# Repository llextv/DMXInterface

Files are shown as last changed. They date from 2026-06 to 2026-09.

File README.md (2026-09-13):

# DMX Interface — ArtNet to DMX Converter

A DIY Ethernet-to-DMX interface designed to convert **Art-Net DMX data into physical DMX512 outputs**.

The goal of this project is to create an affordable alternative to commercial Art-Net to DMX interfaces while keeping the hardware simple, easy to assemble and fully customizable.

---

# Overview

## What does this project do?

This interface acts as a bridge between an Ethernet network and DMX lighting equipment.

Instead of connecting a lighting controller directly to a DMX cable, the controller sends DMX data over an Ethernet network using the **Art-Net protocol**.

This makes the interface particularly useful for **DMX lighting, stage lighting, DJ setups, architectural lighting and other Art-Net compatible applications**.

---

# Hardware

The complete Bill of Materials is available in:

[BOM.csv](BOM.csv)

The detailed BOM is also available at the end of this document.

---

# Mechanical Design

The enclosure was designed to be **fully 3D printable**.

The objective was to avoid requiring specialized machining or industrial manufacturing equipment.

The enclosure can therefore be reproduced using a standard FDM 3D printer.

## Case

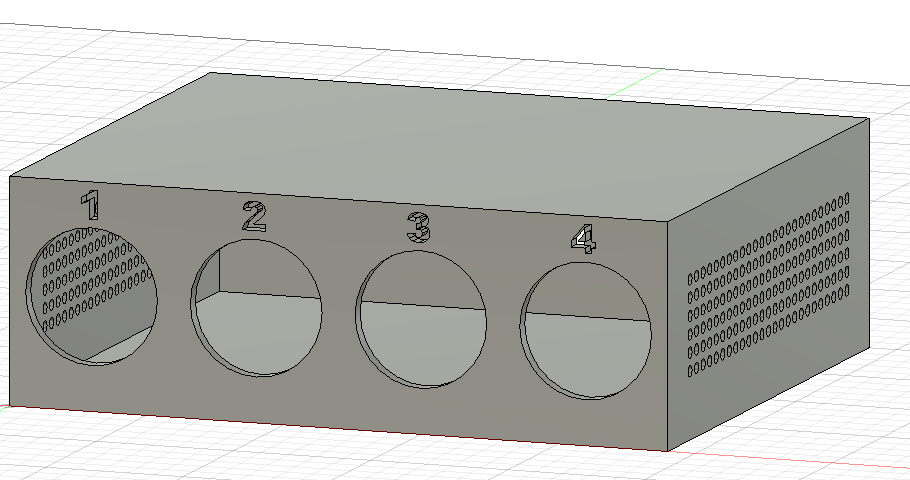
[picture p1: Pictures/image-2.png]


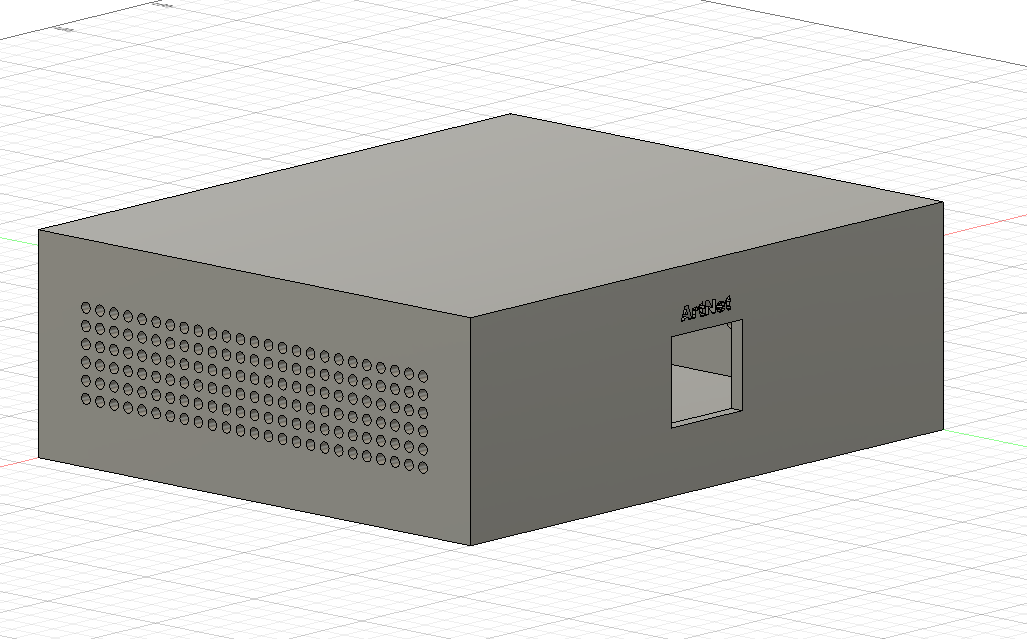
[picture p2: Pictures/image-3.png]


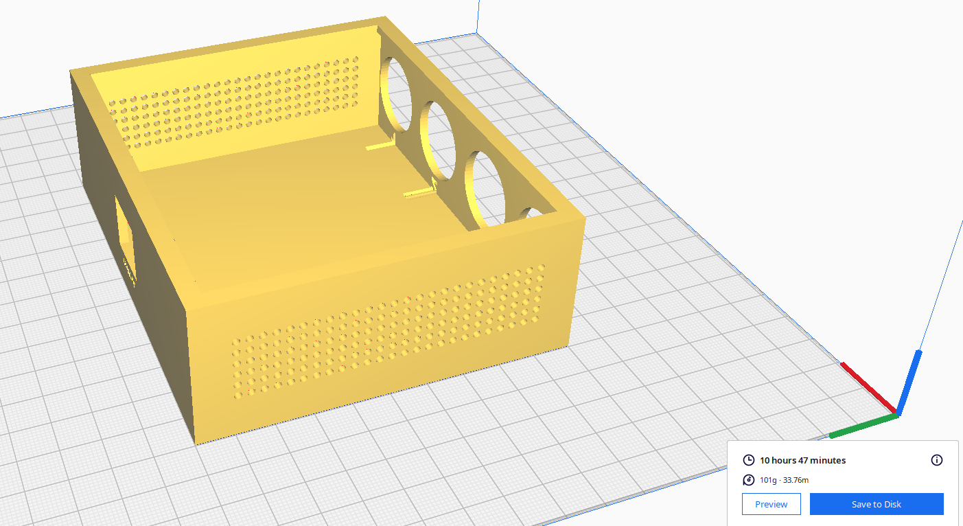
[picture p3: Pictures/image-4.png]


---

# CAD Files

The CAD files are provided in STEP format so that the enclosure can be modified using most modern CAD software.

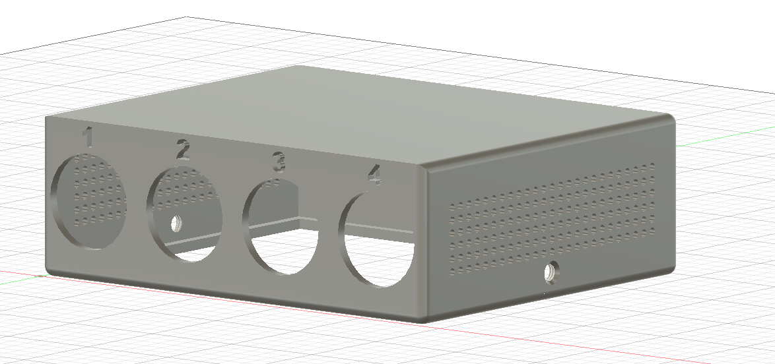
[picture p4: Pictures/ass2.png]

* [Bottom DMX Interface](cad/BottomDMXInterface.step)
* [DMX Interface Enclosure](cad/DMXInterface.step)
* [Assembly](cad\AssemblageDMXInterfaceF.step)

---

# Electronic Design

## Schematic

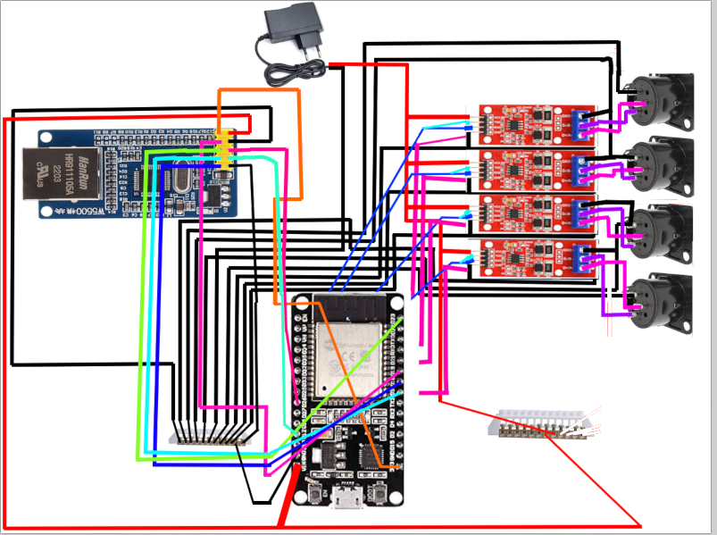
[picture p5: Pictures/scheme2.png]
DMX Interface schematic


The electronics are divided into three main sections:

---

# Firmware

The firmware is responsible for converting Art-Net packets into DMX data.

The current implementation uses an ESP32 together with the following libraries:

* `Ethernet_Generic`
* `ArtnetWifi`
* `ESP32DMX`

---

# Firmware Configuration

The firmware currently uses a static IP address:

```cpp
IPAddress ip(192, 168, 1, 50);
```

This can be changed to match the network used for the lighting setup.

The W5500 chip select pin is configured as:

```cpp
#define W5500_CS 10
```

The four DMX transmit pins are:

```cpp
#define DMX1_TX 4
#define DMX2_TX 5
#define DMX3_TX 6
#define DMX4_TX 7
```

These values must match the actual wiring of the ESP32.

---

# Main Firmware

```c
#include <SPI.h>
#include <Ethernet_Generic.h>
#include <ArtnetWifi.h>
#include <ESP32DMX.h>

#define W5500_CS 10

byte mac[] = {
  0xDE, 0xAD, 0xBE, 0xEF, 0xFE, 0x01
};

IPAddress ip(192, 168, 1, 50);

#define DMX1_TX 4
#define DMX2_TX 5
#define DMX3_TX 6
#define DMX4_TX 7

ESP32DMX dmx1;
ESP32DMX dmx2;
ESP32DMX dmx3;
ESP32DMX dmx4;

uint8_t universe0[512];
uint8_t universe1[512];
uint8_t universe2[512];
uint8_t universe3[512];

ArtnetWifi artnet;

void onDmxFrame(
  uint16_t universe,
  uint16_t length,
  uint8_t sequence,
  uint8_t* data
) {
  switch (universe) {
    case 0:
      memcpy(universe0, data, length);

      for (int i = 0; i < length; i++)
        dmx1.write(i + 1, data[i]);

      break;

    case 1:
      memcpy(universe1, data, length);

      for (int i = 0; i < length; i++)
        dmx2.write(i + 1, data[i]);

      break;

    case 2:
      memcpy(universe2, data, length);

      for (int i = 0; i < length; i++)
        dmx3.write(i + 1, data[i]);

      break;

    case 3:
      memcpy(universe3, data, length);

      for (int i = 0; i < length; i++)
        dmx4.write(i + 1, data[i]);

      break;
  }
}

void setup()
{
  Serial.begin(115200);

  Serial.println("DMX Interface Starting");

  Ethernet.init(W5500_CS);
  Ethernet.begin(mac, ip);

  Serial.print("IP: ");
  Serial.println(Ethernet.localIP());

  dmx1.init(DMX1_TX);
  dmx2.init(DMX2_TX);
  dmx3.init(DMX3_TX);
  dmx4.init(DMX4_TX);

  artnet.begin();
  artnet.setArtDmxCallback(onDmxFrame);

  Serial.println("ArtNet Ready");
}

void loop()
{
  artnet.read();
}
```

---

# BOM

| Category | Item | Quantity | Unit Price (€) | Total (€) | Notes |
| --- | --- | ---: | ---: | ---: | --- |
| Communication | W5500 | 1 | 3.89 | 3.89 | Ethernet controller |
| Communication | MAX3485 Module RS-485 | 4 | 1.40 | 5.60 | One per DMX output |
| Controls | ESP-WROOM-32 | 1 | 5.89 | 5.89 | Main controller |
| Connectique | XLR 3Pin Panel Mount Connectors Female | 4 | 1.05 | 4.19 | Lot of 4 connectors |
| Power | 5V 2A Power Supply | 1 | 2.99 | 2.99 | Main power supply |
| Prototype | 12 Holes Bridge | 2 | 2.37 | 4.74 | Electrical connections |
| **TOTAL** | | | | **27.30 €** | |

---

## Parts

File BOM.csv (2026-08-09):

Categorie | Article | Quantite | Prix_Unitaire_EUR | Prix_Total_EUR | Notes | URL
Communication | W5500 | 1 | 3.89 | 3.89 |  | https://fr.aliexpress.com/item/1005009353017777.html
Communication | MAX3485 Module RS-485 | 4 | 1.40 | 5.6 |  | https://fr.aliexpress.com/item/1005006007545162.html
Controls | ESP-WROOM-32 | 1 | 5.89 | 5.89 |  | https://fr.aliexpress.com/item/1005012697513614.html
Connectique | XLR 3Pin Panel Mount Connectors Female | 4 | 1.05 | 4.19 | Lot de 4 connecteurs | https://fr.aliexpress.com/item/1005008919369057.html
Power | Alimentation 5V 2A | 1 | 2.99 | 2.99 |  | https://fr.aliexpress.com/item/1005005539475429.html
Prototype | 12 Holes Bridge | 2 | 2.37 | 4.74 |  | https://fr.aliexpress.com/item/1005001742109041.html
TOTAL |  |  | 27,3

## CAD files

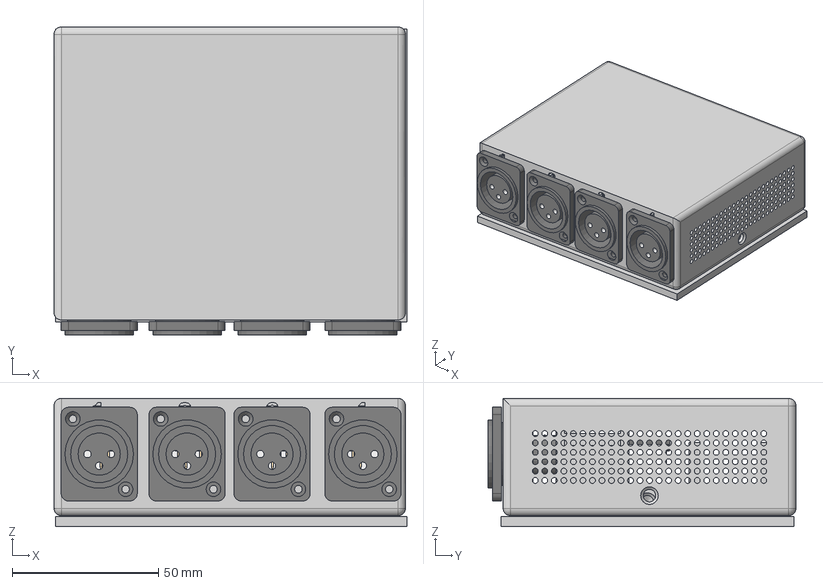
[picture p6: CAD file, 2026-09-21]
cad/AssemblageDMXInterfaceF.step
120.5 x 105.2 x 43.7 mm
plug_rj45
ESPBlock
BottomDMXInterface
DMXInterface
2 PIN - DG306-5 - PITCH 5 mm v1 x 4
Black Pin H 2.5mm-6mm-3mm x4 v1 x 8
MAX485CUA v1 x 4
MAX485 Block x 4
ESP-WROOM-32
DMX port v1 x 4

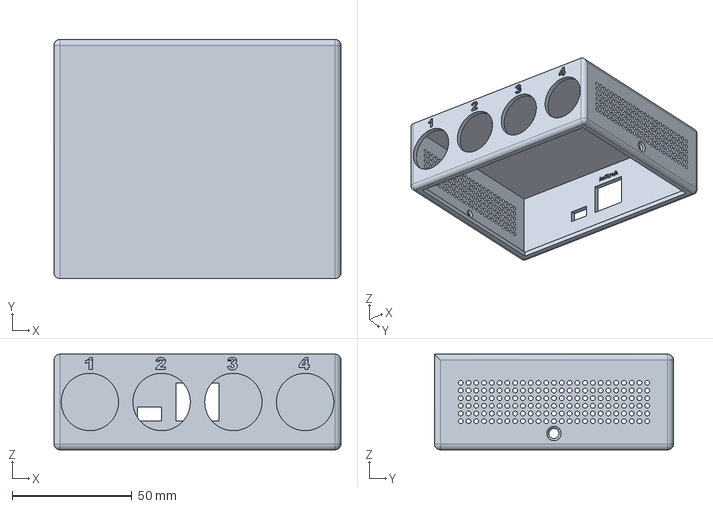
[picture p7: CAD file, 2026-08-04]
cad/DMXInterface.step
120.0 x 100.0 x 40.0 mm

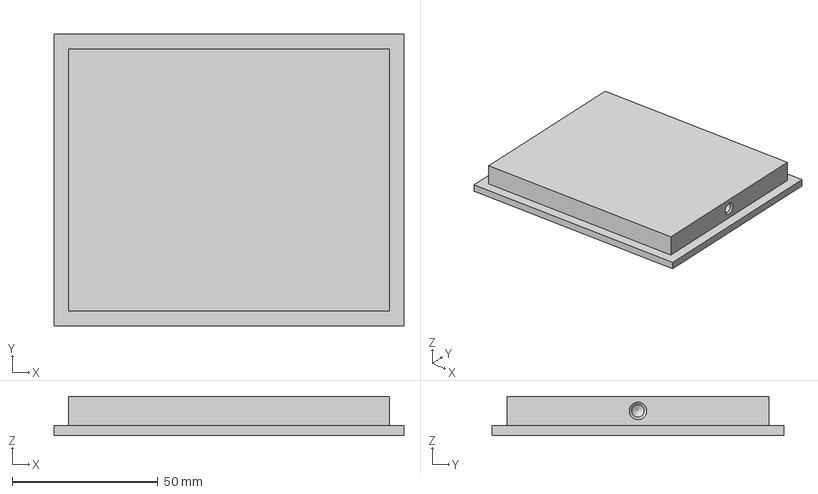
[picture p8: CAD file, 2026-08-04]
cad/BottomDMXInterface.step
120.0 x 100.0 x 13.5 mm

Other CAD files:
cad/AssemblageDMXInterface.f3z

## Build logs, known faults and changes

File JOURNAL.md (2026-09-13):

---
title: "DMXInterface"
author: "llextv"
description: "An interface between Ethernet --> DMX (ArtNet to DMX)"
created_at: "2026-06-17"
---

# June 17: Defining system & BOM test
I would like to create a system base on ESP with two main component:
-> DMX Interface
-> Ethernet Interface

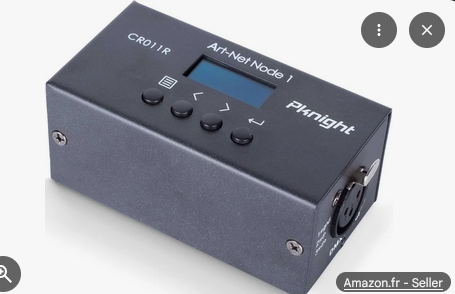
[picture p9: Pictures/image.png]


Management of 4 universe is good so we need 4 DMX interface and software for distribute DMX to good interface

This Interface need to be compaptible with QLC+ for DMX Management with ArtNet difusion on 4 universe.

I've work on my BOM with all documentation, choice of ESP32-S3 to management better and efficency 4 universe.

**Preview BOM:**
-> W5500 (https://fr.aliexpress.com/item/1005009353017777.html) = 3,89€
-> 4 * MAX485 Module RS-485 (https://fr.aliexpress.com/item/1005007011742123.html) = 0.83€ * 4 = 3,32€
-> ESP32-S3 (https://fr.aliexpress.com/item/1005012092039320.html) = 5.69€
-> 4 * XLR 3Pin Panel Mount Connectors Female (https://fr.aliexpress.com/item/1005008919369057.html) = 4.19€
-> 5V 2A Alimentation (https://fr.aliexpress.com/item/1005005539475429.html) = 2.99€
-> 2 * 12 Holes Bridge (https://fr.aliexpress.com/item/1005001742109041.html) = 2 * 1,37€ = 4,74€

I will made a little box in PLA with my 3D Printer for put all component but no PCB needed for this project, I have cable at home for this project.

**Total time spent: 3 hours**

# June 18: Electric scheme
I made electrical scheme with all component:
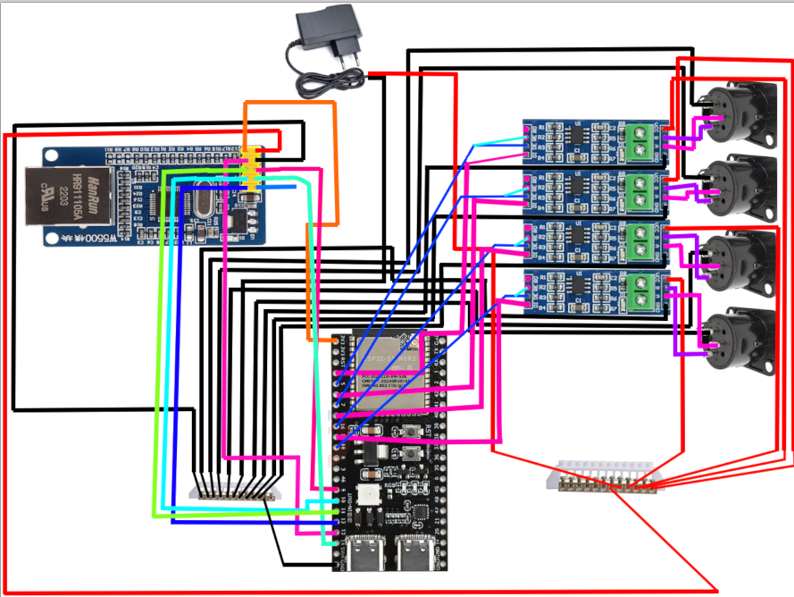
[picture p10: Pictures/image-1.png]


For a total of 24,82€ arround $28,55

One of my actual question is on Alimentation (Jack at the base) but I will try to cut the cable and sort +5V and GND cable from this

I spend lot of time in my scheme (ChatGPT fail for response me with the PIN of W5500 and no technical docs ?)

**Total time spent: 2 hours**

# June 19: Casing in fusion 360
Beautiful casing made on Fusion 360:



This case sliced:


101g of 3d filament + bottom plate for finish the build (I need 250g of filament from forge I will make demand for this)

**Total time spent: 2 hours**

# June 20: Development
I made the code of my project (Help with AI for debug):
```c
#include <SPI.h>
#include <Ethernet_Generic.h>
#include <ArtnetWifi.h>
#include <ESP32DMX.h>

#define W5500_CS 10

byte mac[] = {
  0xDE, 0xAD, 0xBE, 0xEF, 0xFE, 0x01
};

IPAddress ip(192, 168, 1, 50);

#define DMX1_TX 4
#define DMX2_TX 5
#define DMX3_TX 6
#define DMX4_TX 7

ESP32DMX dmx1;
ESP32DMX dmx2;
ESP32DMX dmx3;
ESP32DMX dmx4;

uint8_t universe0[512];
uint8_t universe1[512];
uint8_t universe2[512];
uint8_t universe3[512];

ArtnetWifi artnet;

void onDmxFrame(uint16_t universe, uint16_t length, uint8_t sequence, uint8_t* data){
  switch (universe)
  {
    case 0:
      memcpy(universe0, data, length);
      for(int i=0;i<length;i++)
        dmx1.write(i + 1, data[i]);
      break;
    case 1:
      memcpy(universe1, data, length);
      for(int i=0;i<length;i++)
        dmx2.write(i + 1, data[i]);
      break;
    case 2:
      memcpy(universe2, data, length);
      for(int i=0;i<length;i++)
        dmx3.write(i + 1, data[i]);
      break;
    case 3:
      memcpy(universe3, data, length);
      for(int i=0;i<length;i++)
        dmx4.write(i + 1, data[i]);
      break;
  }
}

void setup()
{
  Serial.begin(115200);
  Serial.println("DMX Interface Starting");
  Ethernet.init(W5500_CS);
  Ethernet.begin(mac, ip);
  Serial.print("IP: ");
  Serial.println(Ethernet.localIP());
  dmx1.init(DMX1_TX);
  dmx2.init(DMX2_TX);
  dmx3.init(DMX3_TX);
  dmx4.init(DMX4_TX);
  artnet.begin();
  artnet.setArtDmxCallback(onDmxFrame);
  Serial.println("ArtNet Ready");
}

void loop()
{
  artnet.read();
}
```
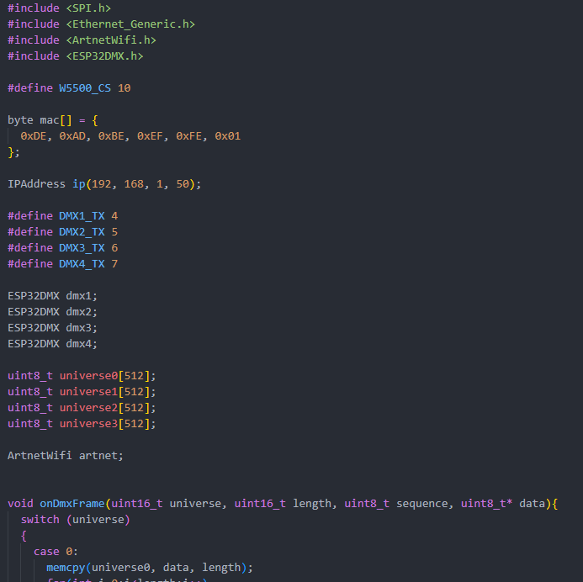
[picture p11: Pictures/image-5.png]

It's works for compil but I have trouble with my dev ESP card at home, I search for issue but find nothing, it's can be in ESP32DMX lib 

For config in QLC+:

Cable ethernet with PC and config QLC with this:

Output: ArtNet
IP: Ethernet.localIP()
Universe 0 -> DMX OUT 1
Universe 1 -> DMX OUT 2
Universe 2 -> DMX OUT 3
Universe 3 -> DMX OUT 4

**Total time spent: 2 hours**

# July 18 & 19: Response about changes needed
I receive this message:
Hey, nice project and amazing effort, but there is few things to fix before getting approved!

    You need to have solid way to mount the electronic components inside your case. Try designing holder OR make holes in your case so you can use screws and nuts to mount them.
    Regarding schematics, you have connected the red wire from the external power adapter directly to the ESP32’s 3V3 pin. This will send too much voltage (5V+) into the ESP32’s internal 3.3V line, which could destroy the main chip. Try connecting it to 5V.

So two problems:
- schematic with 5V injected in ESP
- casing with no block system for card

For solution of first problem:
An idea is to change the card ESP-C3 to ESP-WROOM-32, I test at home, it's works, for 5.89€ so it's lower than ESP-C3 and 5V pin are here ...

So new BOM:

| Catégorie | Article | Quantité | Prix unitaire (€) | Prix total (€) | Notes | URL |
| --- | --- | ---: | ---: | ---: | --- | --- |
| Communication | W5500 | 1 | 3.89 | 3.89 | | [https://fr.aliexpress.com/item/1005009353017777.html](https://fr.aliexpress.com/item/1005009353017777.html) |
| Communication | MAX485 Module RS-485 | 4 | 0.83 | 3.32 | | [https://fr.aliexpress.com/item/1005007011742123.html](https://fr.aliexpress.com/item/1005007011742123.html) |
| Controls | ESP32-WROOM-32 | 1 | 5.89 | 5.89 | | [https://fr.aliexpress.com/item/1005012697513614.html](https://fr.aliexpress.com/item/1005012697513614.html) |
| Connectique | XLR 3Pin Panel Mount Connectors Female | 4 | 1.05 | 4.19 | Lot de 4 connecteurs | [https://fr.aliexpress.com/item/1005008919369057.html](https://fr.aliexpress.com/item/1005008919369057.html) |
| Power | Alimentation 5V 2A | 1 | 2.99 | 2.99 | | [https://fr.aliexpress.com/item/1005005539475429.html](https://fr.aliexpress.com/item/1005005539475429.html) |
| Prototype | 12 Holes Bridge | 2 | 2.37 | 4.74 | | [https://fr.aliexpress.com/item/1005001742109041.html](https://fr.aliexpress.com/item/1005001742109041.html) |
| **TOTAL** | | | | **25.02** | | |

New scheme:
[Scheme](assets\DMXInterface.pdn)

I made this for block ESP-WROOM-32
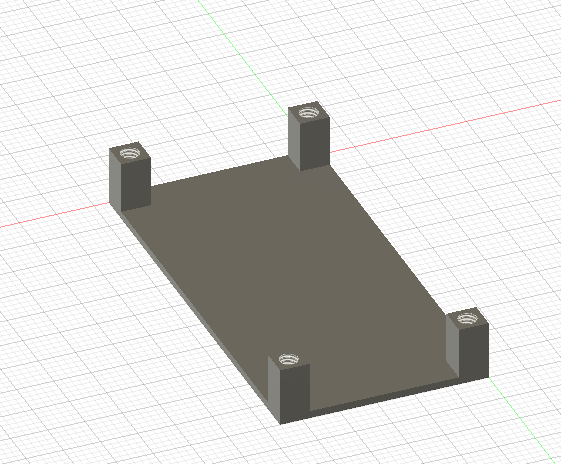
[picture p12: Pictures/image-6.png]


This for block MAX485
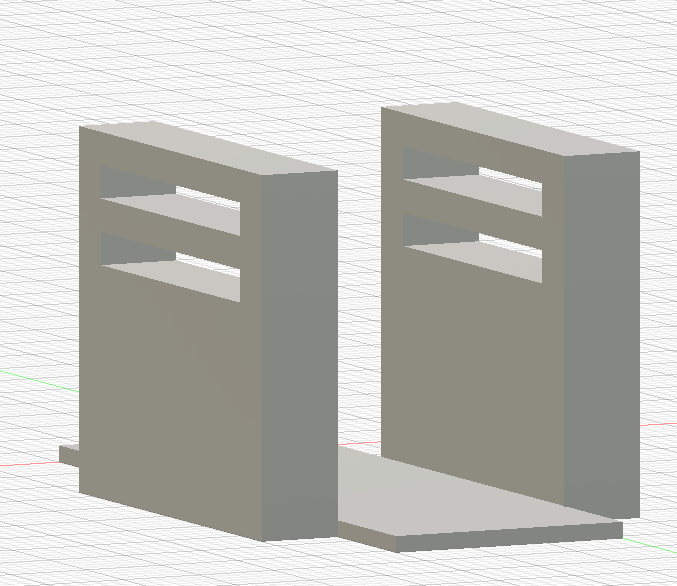
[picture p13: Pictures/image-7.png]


This is monting on assembly
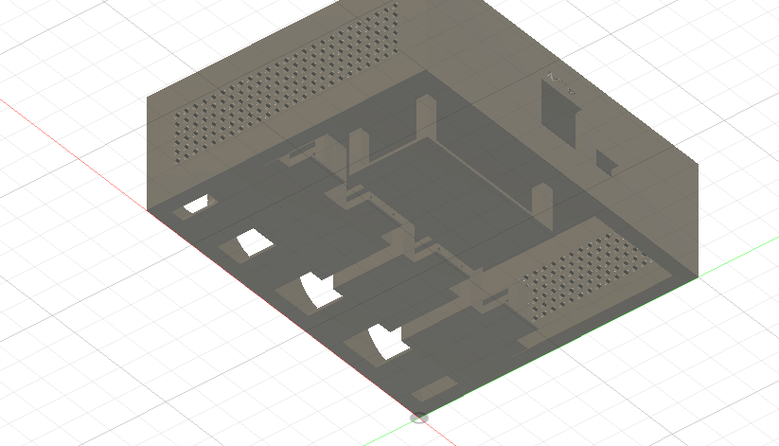
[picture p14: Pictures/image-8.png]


**Total time spent: 3.5 hours**

# New response !
I have received this message:
"Hi, this is a cool project, and the idea is really interesting, but it needs some polishing before we can accept it! It doesn't have a custom PCB, and that's totally fine, but that means that your case should be a bit more refined. Right now I don't see how the different parts are supposed to stay together, and there's no base on your container! I don't know how much CAD experience you have, but this is a great opportunity to learn it better. I'd love to see a design-optimized case with a removable back panel, easy screw & heatset insert mounts for the esp32 and other components, and maybe even dedicated wire paths and routing helps to make it extra satisfying and easy to set up. Overall, I love the idea, but I'd just like to see it worked through a little more."

3 problems detected in your message:

The container/enclosure does not have a base.
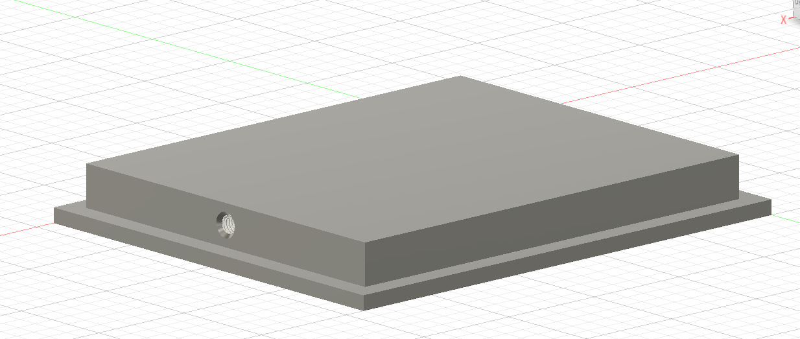
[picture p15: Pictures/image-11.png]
-> 
The case design is not refined enough.
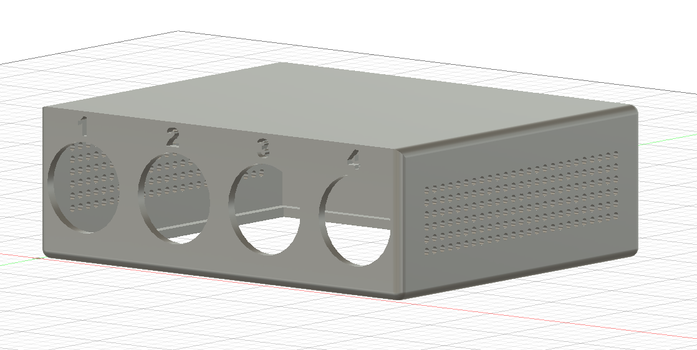
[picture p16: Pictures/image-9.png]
->  I polish it
No screw mounts or heat-set insert locations are included.
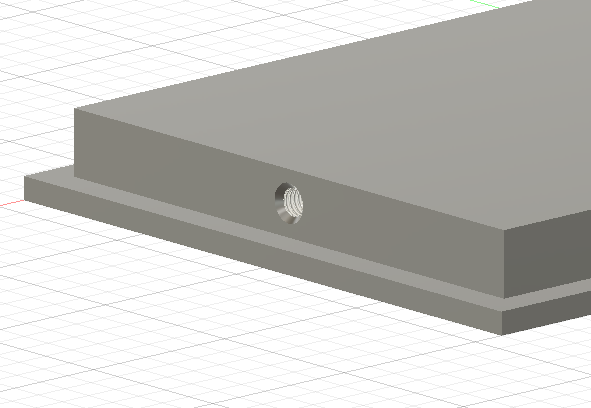
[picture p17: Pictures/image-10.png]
->
I made hole in my case

I remade render and assembly for this
assets\DMXInterface.step
assets\BottomDMXInterface.step
assets\AssemblageDMXInterface.step

**Total time spent: 2.5 hours**

# New response ! Pt 2
I received:
"Hi! great work, but please add a complete CAD assembly, with all components (including electronics). you can download cad of the components from grab cad and position them to their assigned places, it will help us in finding any issues (if exists). Also please organize the repo, add all the images in a folder, you can also improve your readme formatting (it will greatly improve the looks of your readme), please do the required changes and we will have another look :)"

So problems are:
- Images folder (organisation of repo)
-> Good
- README ameliorations
-> its good
- CAD Assembly files
-> exported :)
- Add mecanic components
-> This is good:
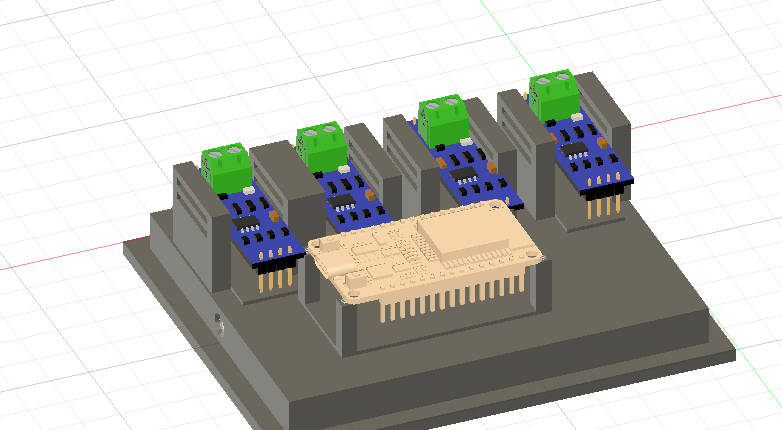
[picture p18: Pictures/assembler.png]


**Total time spent: 0.5 hours**

# New response ! Pt 3
I reveived: 
"Hi! Nice project, but there are a few problems rn that need to be fixed:

    your repo is not organised; it'd be great if you put respective files into their respective folders, such as cad/, firmware/, etc.
    I don't see a way on how you are going to assemble your enclosure.
    The MAX485 module that you are using right now works on 5V logic, but your ESP32 works on 3.3V logic; this will fry your MCU. Please have a voltage divider/level shifter. It'd be better if you used any other 3.3v logic modules, such as those based on MAX3485.
    Not required though, but schematic made in kicad would generally be more easier to read than this one.
"

--> Organisation of repo ==> OK !
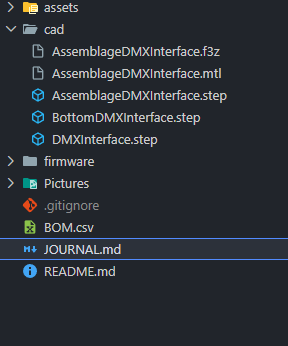
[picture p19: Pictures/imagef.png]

--> Assembly ==> I add it
--> MAX485 ==> I changed it to MAX3485 (https://fr.aliexpress.com/item/1005006007545162.html) and update BOM but nothing change on scheme
--> I havent KiCad scheme but now I made one for each project

**Total time spent: 0.5 hours**

# New message = new scheme
I received:
you've changed the rs-485 transceiver from the max485 to the max3485 in your bom, but the wiring diagram still shows the old max485 modules. please update the diagram to show the exact max3485 modules being used and make sure the connections match the final design.

so It's now patched !

**Total time spent: 0.25 hours**

# New message Pt 5
"Hi, nice project, but you need a bom in your readme file"
I made a new BOM in readme so it's patched !
Thanks for your time and your response
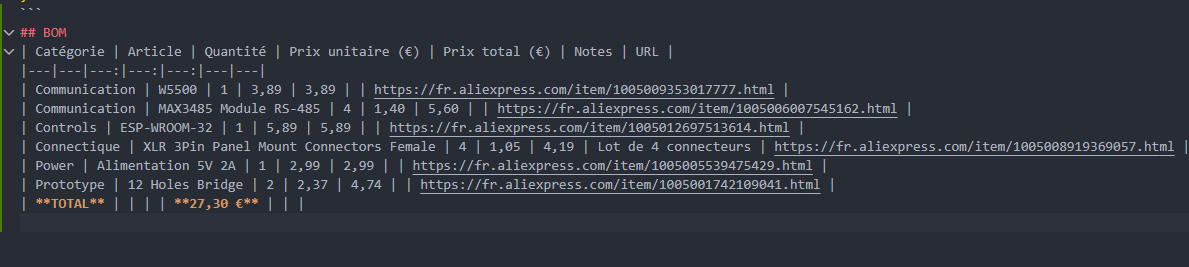
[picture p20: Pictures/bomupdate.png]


**Total time spent: 0.1 hours**

# New message Pt 6
I received: hey, nice project, but you need a full cad assembly of your project with electronics in your repo, both the file and pictures

Thanks for your time
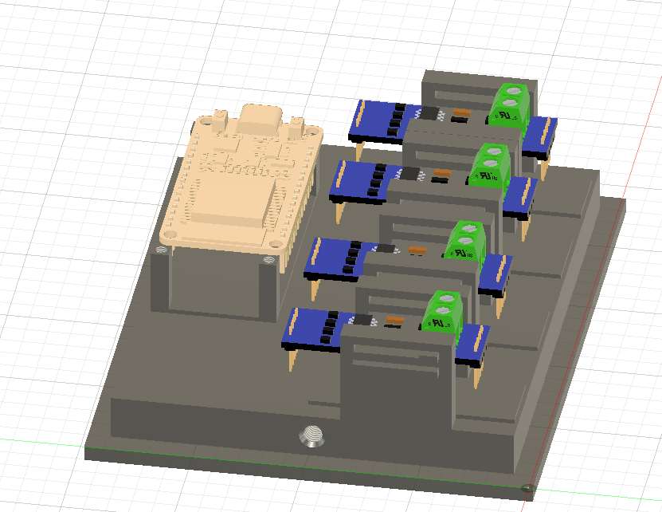
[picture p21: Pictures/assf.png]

It's updated !

**Total time spent: 0.2 hours**

# New message Pt 7
I received: 
Cool project! There's a couple changes that need to be made:

    The case needs to be polished a bit more, especially because you're not using a custom PCB/perfboard
    Please make your README more detailed - explain some more about what your project does and what the process of building it would be like

This is looking really good! Make those changes and send it back!

I finish polishing it with edit of Case file & Bottom file:
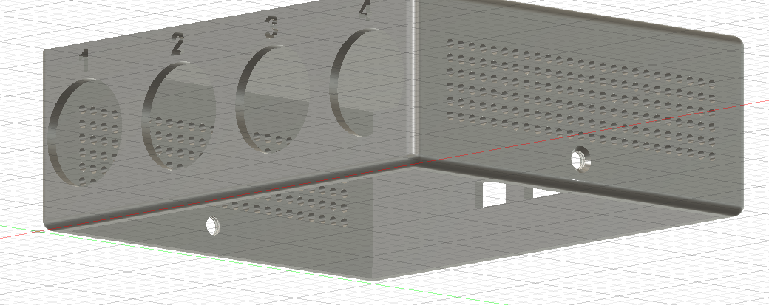
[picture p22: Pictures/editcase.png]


and I edit README
I write it and ask AI to transform it in good english and good Markdown

**Total time spent: 0.5 hours**

# New message Pt 8
I received:
hiii your read me seems to be re written by an llm please write it yourself!

So I update it
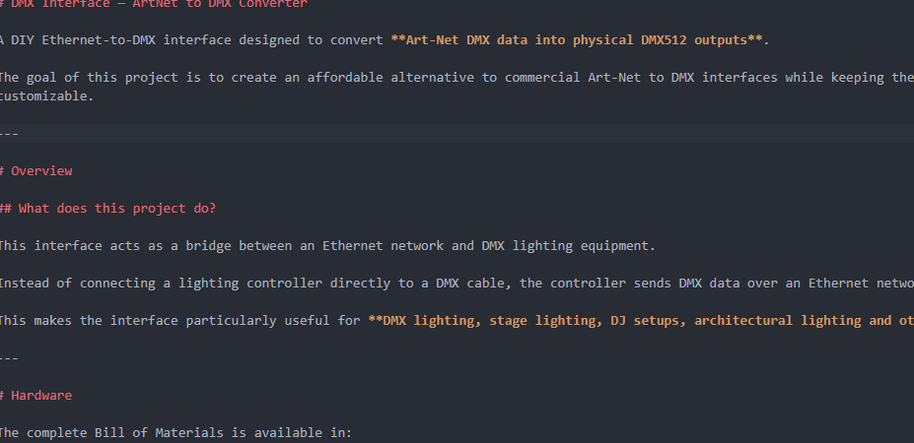
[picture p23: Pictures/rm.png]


**Total time spent: 0.15 hours**

# New message Pt 9
I received:
Hey there! I noticed that you polished in your case in a past journal, could you please update your README with the new case and also create a full assembly that puts the base with all the electronics, into your larger enclosure to show how everything fits together

So I just update the README & assembly
DMX Interface enclosure

**Total time spent: 0.15 hours**

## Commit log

2026-06-20 day 4
    [BOM.csv, DMXInterface.f3d]
2026-07-19 Day 5
    [AssemblageDMXInterface.f3z, AssemblageDMXInterface.step, DMXInterface.f3d]
2026-07-19 Day 5.2
    [BOM.csv]
2026-08-04 Day 6
    [AssemblageDMXInterface.f3z, AssemblageDMXInterface.step, BottomDMXInterface.step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]
2026-08-06 Day 7
    [AssemblageDMXInterface.step]
2026-08-06 Day 7.2
    [AssemblageDMXInterface.f3z]
2026-08-09 Day 8
    [AssemblageDMXInterface.f3z, AssemblageDMXInterface.step, BottomDMXInterface.step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]
2026-08-09 Day 8.2
    [BOM.csv]
2026-08-19 Day 11
    [AssemblageDMXInterface.step]
2026-09-13 Day 14
    [AssemblageDMXInterface.step, AssemblageDMXInterfaceF.step]
2026-09-21 Day 15
    [AssemblageDMXInterfaceF.step]
2026-11-08 Fix image link for DMX Interface enclosure
    Updated image link for DMX Interface enclosure in README.
2026-11-08 Fix assembly file link in README
    Updated the assembly file link in the README.
